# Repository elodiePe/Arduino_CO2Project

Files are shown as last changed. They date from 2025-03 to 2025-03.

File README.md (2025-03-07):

# GameAir

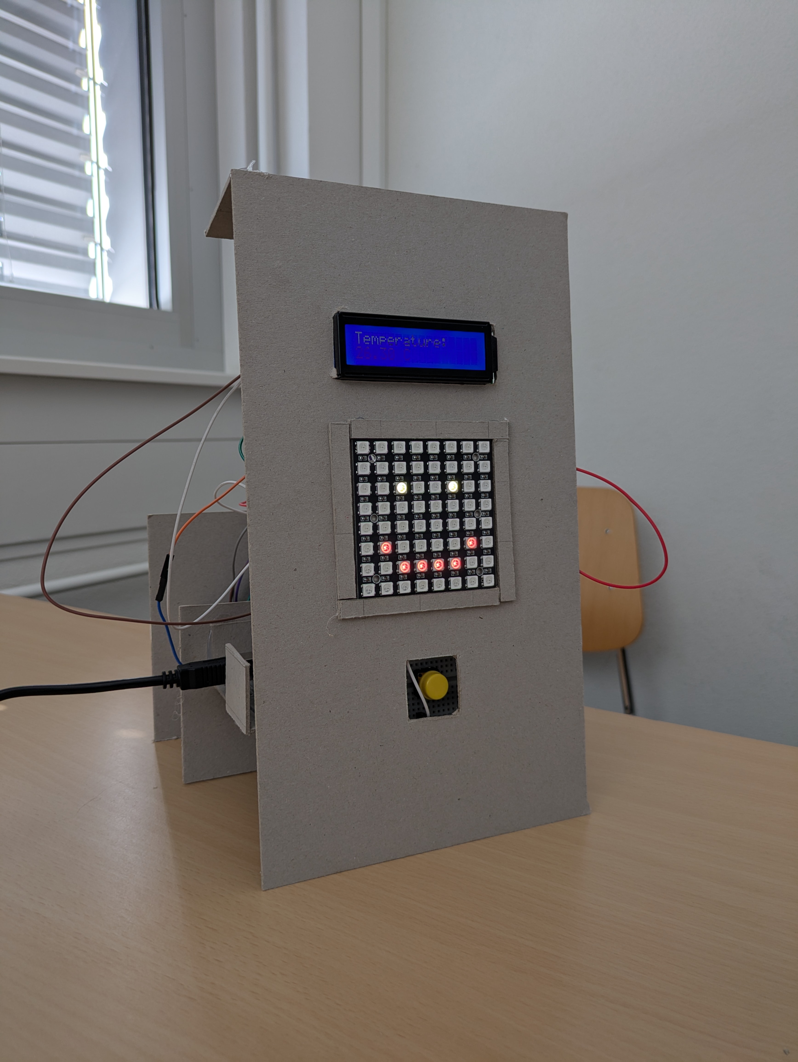
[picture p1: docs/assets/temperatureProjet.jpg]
Description de l'image


Réalisé par `Elodie Perring`
Option Arduino 2025 – COMEM+

---

## Description

`GameAir est un projet Arduino qui a pour but de détecter la qualité de l'air. Ce projet utilise plusieurs composants : un détecteur de CO2, un détecteur de température/humidité, un détecteur de mouvement,une matrice de LED rgb, un écran LCD ainsi qu'un bouton.`

## Documentation

Retrouvez la documentation dans le dossier [docs](docs/).

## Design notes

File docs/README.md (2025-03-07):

# Documentation

## Recherche et conception

Dans les salles de classe, il fait souvent chaud et elles manquent d'aération, ce qui réduit la quantité d'oxygène disponible et impacte la concentration. C'est pour cette raison que j'ai saisi l'opportunité de créer un détecteur de qualité de l'air afin de remédier à ce problème.

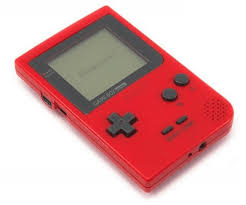
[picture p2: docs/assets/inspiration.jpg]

>Source : https://www.u-buy.ch/fr/product/47MMJS6W0-authentic-nintendo-gameboy-pocket-red-100-oem

Pour rendre le dispositif à la fois ludique et attrayant, je me suis inspirée du design des Game Boys et des anciennes consoles de jeux vidéo. Le projet, baptisé GameAir, propose plusieurs fonctionnalités afin d’offrir une expérience complète et utile :

- **Affichage de la température sur un écran LCD** : En fonction de la température (chaud, froid ou tempéré), un smiley correspondant apparaît sur la matrice de LED RGB.

- **Affichage du taux d'humidité** : plus le taux d'humidité est élevé, plus les LEDs s'allument sur la matrice pour une représentation visuelle immédiate.!
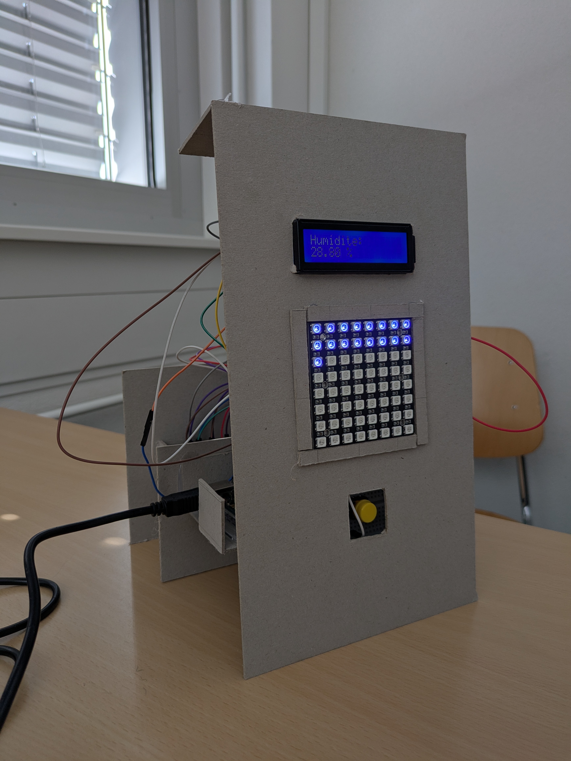
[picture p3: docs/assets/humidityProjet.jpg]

- **Affichage du niveau de CO2** : lorsque le taux de CO2 dépasse 1000 ppm (sur la photo et la video la limite est à 400), un symbole d'alerte apparaît sur la matrice de LED, et un buzzer retentit toutes les 3 minutes tant que la concentration reste trop élevée. [Voir la video](video_projet.mp4)
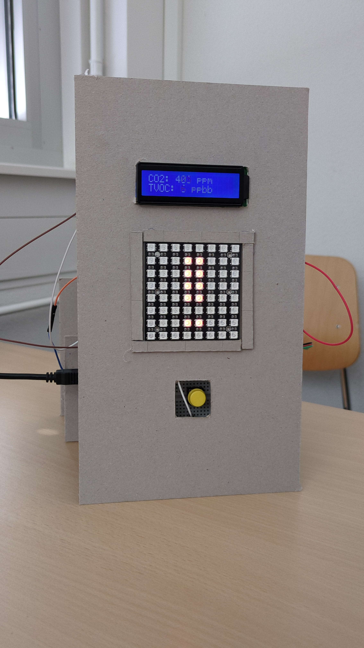
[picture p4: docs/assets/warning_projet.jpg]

- **Détecteur de mouvement intégré** : si aucune présence n'est détectée, les écrans restent éteints. En revanche, dès qu'une personne est présente, les écrans s'allument automatiquement.

### Mes prototypes

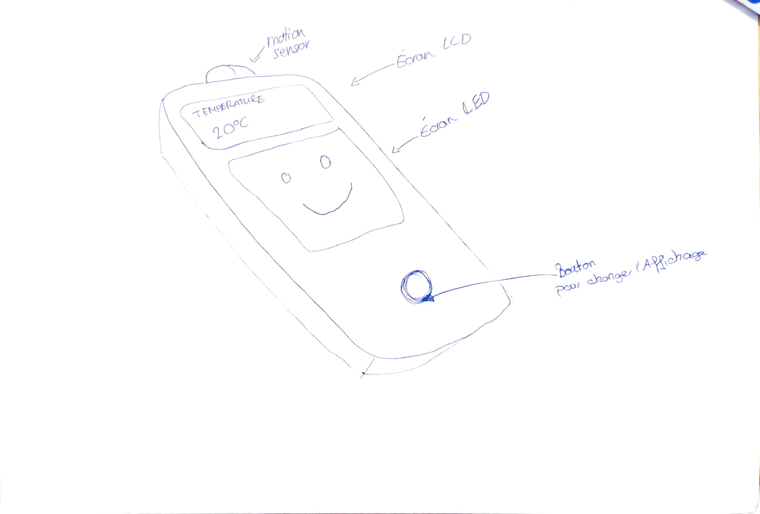
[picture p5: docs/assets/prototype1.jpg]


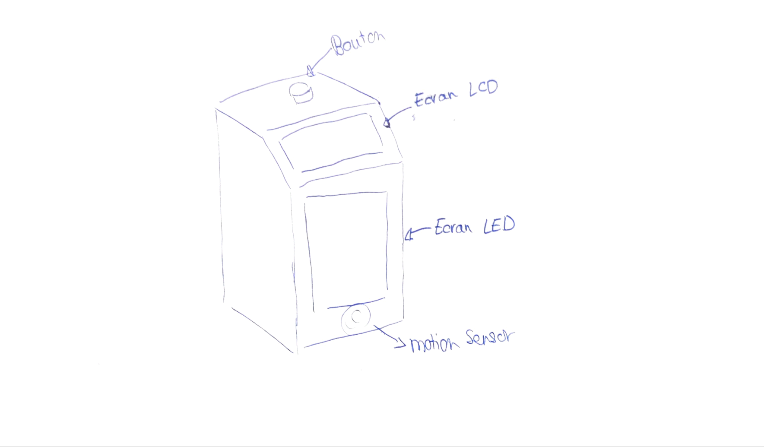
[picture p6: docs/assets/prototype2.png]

<br>

## Circuit électronique

Lors de ce projet, j'ai utilisé plusieurs composants et principalement des capteurs : 
- **Matrice de LED** : J'ai commencé par utiliser [une matrice LED rouge 16x16](matriceLed.md), mais comme le rendu n'étais pas convainquant, j'ai décidé de changer de matrice et d'utiliser la [8X8 matrice RGB de Purecrea](https://download.bastelgarage.ch/Datasheet/WS2812_Datasheet.pdf). Cette matrice est beaucoup plus simple à utiliser notamement grâce aux librairies déjà existantes.
- **Ecran LCD** : Grâce à la librairie déjà existante, cet écran est simple à utiliser. [Lien vers la datasheet](https://cdn-shop.adafruit.com/datasheets/TC1602A-01T.pdf)
- **Buzzer Piezo**
- **Capteur de mouvement** : J'ai utilisé le [PIR HC-SR501](motion.md)
- **Capteur de C02** : J'ai utiliser le [SGP30](co2.md)
- **Capteur de température & de l'humidité** : J'ai utilisé le [DHT11 temperature and humidity sensor](temp.md)

### Schéma

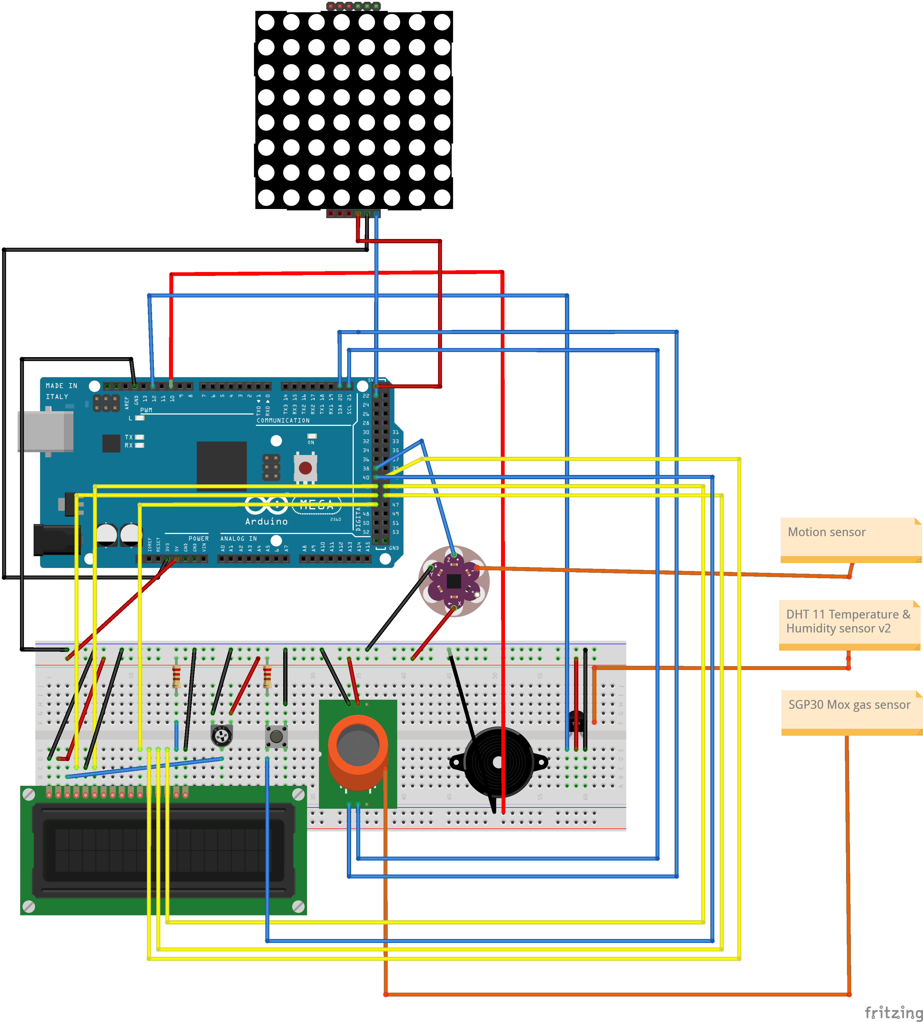
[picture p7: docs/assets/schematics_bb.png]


### BOM

|  | Composant | Quantité | Description | Fournisseur / Lien |
| --- | --- | --- | --- | --- |
| 1 | arduino mega 2560 | 1 | microcontroller  ATmega2560 | [Arduino](https://store.arduino.cc/products/arduino-mega-2560-rev3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) |
| 2 | Breadboard | 2 | Plaque de prototypage | [Digitec](https://www.digitec.ch/en/s1/product/velleman-high-quality-plug-in-board-electronics-supplies-casing-6337139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) |
| 3 | LCD screen  | 1 | 16x2 (6,6cm) | [Conrad](https://www.conrad.ch/de/p/joy-it-com-lcd-16x2-display-modul-6-6-cm-2-6-zoll-16-x-4-pixel-passend-fuer-entwicklungskits-arduino-mit-hintergrund-1656369.html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) |
| 4  | Buzzer Piezo  | 1 | 1,5V | [Digikey](https://www.digikey.ch/de/products/detail/murata-electronics/PKM22EPPH2001-B0/1219322?productid=1219322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)
| 5 | 8x8 LED matrix  | 1 | Purecrea NeoPixel NeoMatrix 8x8 - 64 WS2812 RGB LED | [Digitec](https://www.digitec.ch/de/s1/product/purecrea-neopixel-neomatrix-8x8-64-ws2812-rgb-led-aktive-bauelemente-36133371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) 
| 6 | Détecteur de mouvements  | 1 | Module détecteur de mouvement PIR Purecrea HC-SR501 | [Digitec](https://www.digitec.ch/de/s1/product/purecrea-hc-sr501-pir-bewegungsmelder-modul-entwicklungsboard-kit-39552366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) 
| 7 | Gas Sensor SGP30  | 1 | Gaz, humidité, qualité de l'air intérieur (QAI) | [DigiKey](https://www.digikey.ch/de/products/detail/adafruit-industries-llc/3709/8258468?productid=8258468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)  
| 8 | Temperature and humidity sensor  | 1 | DHT11 Temperature and Humidity Sensor  | [DFrobot](https://wiki.dfrobot.com/DHT11_Temperature_and_Humidity_Sensor__SKU__DFR0067_) 
| 9 | Bouton  | 1 | Bouton  | [Digitec](https://www.digitec.ch/de/s1/product/purecrea-taster-button-set-25-stueck-diverse-farben-taster-schalter-39044933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) 
| 10 | Resitance  | 2 | Résitances  | [DFrobot](https://www.digitec.ch/de/s1/product/kemo-widerstands-set-widerstand-21606532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) 
| 11 | Potentiomètre  | 1 | Potentiomètre  | [Digitec](https://www.digitec.ch/de/s1/product/purecrea-10k-ohm-linear-drehpotentiometer-3386p-1-103-potentiometer-passive-bauelemente-36225564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) 

## Programme
Dans ce projet, j'ai utilisé plusieurs librairies pour optimiser les fonctionnalités. La librairie LiquidCrystal me permet de gérer l'affichage sur un écran LCD, essentiel pour afficher des informations comme la température, l'humidité ou encore le niveau de CO2. J'ai également utilisé la librairie DHT pour le capteur d'humidité et de température, et Adafruit_SGP30 pour le capteur de qualité de l'air, mesurant le CO2 et les TVOC. Pour rendre l'interface plus visuelle et ludique, j'ai intégré la librairie FastLED afin de contrôler une matrice LED RGB 8x8, qui affiche des smileys et des indicateurs en fonction des données mesurées.
Pour éviter les rebonds du bouton et permettre au code de gérer plusieurs tâches en parallèle, j'ai utilisé la fonction millis(), ce qui permet de ne pas interrompre le fonctionnement du programme.

## Roadmap
Il y a encore plusieurs points à améliorer dans le projet. Par exemple, le buzzer ne peut pas être arrêté une fois activé, ce qui pourrait rapidement devenir agaçant. De plus, les visuels affichés sur la matrice de LED sont pour l'instant très statiques. Pour rendre l'appareil plus interactif et attractif, il serait intéressant de rendre ces visuels animés ou de les rendre plus dynamiques et détaillés, en intégrant par exemple des transitions ou des animations plus sophistiquées.

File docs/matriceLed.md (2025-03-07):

# Matrice LED 16x16
[Cette matrice](https://www.wiltronics.com.au/product/19744/dot-matrix-16x16-red-led-display-module-arduino-compatible/) de 16x16 (leds rouges) a très peu de documentation en ligne.
## Exemple de code pour afficher des smileys
```C++
// Définition des broches pour le contrôle des LED
const int LEDARRAY_D = 2;
const int LEDARRAY_C = 3;
const int LEDARRAY_B = 4;
const int LEDARRAY_A = 5;
const int LEDARRAY_G = 6;
const int LEDARRAY_DI = 7;
const int LEDARRAY_CLK = 8;
const int LEDARRAY_LAT = 9;

// Le nombre de mots et de caractères à afficher
const int DISPLAY_NUM_WORD = 2;
const int NUM_OF_WORD = 2; // 5 lettres pour "pluie"

unsigned char displayBuffer[8];
unsigned char displaySwapBuffer[DISPLAY_NUM_WORD][32] = { 0 };
bool shiftBit = 0;
bool flagShift = 0;
unsigned char timerCount = 0;
unsigned char temp = 0x80;
unsigned char shiftCount = 0;
unsigned char displayWordCount = 0;
const char happySmiley[2][32] = {
//hAPPY sMILEY
0xF8, 0xE0, 0xC0, 0x86, 0x86,0x06,0x00, 0x20, 
0x30, 0x18, 0x8C, 0x87,0xC0, 0xE0, 0xF8, 0xFF, 
0x3F, 0x0F, 0x07, 0xC3, 0xC3, 0xC1, 0x01, 0x09, 
0x19, 0x31, 0x63, 0xC3, 0x07, 0x0F, 0x3F, 0xFF,
};

const char coldSmiley[2][32] = {
// COLD SMILEY 
0xFF, 0xFF, 0xE7, 0xDB, 0xFF, 0xE7, 0xE7, 0xFF,
0xFF, 0xC0, 0xD6, 0xDA, 0xC0, 0xFF, 0xFF, 0xFF,
0xFF, 0xFF, 0xCF, 0xB7, 0xFF, 0xCF, 0xCF, 0xFF,
0xFF, 0x07, 0xD7, 0xB7, 0x07, 0xFF, 0xFF, 0xFF,
};

const char sunSmiley[2][32] = {
// SMILEY SUN
0xFF, 0xFF, 0x02, 0x80, 0x82, 0x87, 0xFF, 0xFF,
0x3F, 0xDF, 0xCF, 0xEF, 0xF0, 0xFF, 0xFF, 0xFF,
0xFF, 0xFF, 0x07, 0x0F, 0x0F, 0x0F, 0xFF, 0xFF,
0xE7, 0xCF, 0x9F, 0xBF, 0x7F, 0xFF, 0xFF, 0xFF,
};
const char warning[2][32] = {
// WARNING SIGN
0xFF, 0xFE, 0xFD, 0xFB, 0xFA, 0xF6, 0xF6, 0xE6,
0xEE, 0xEF, 0xCE, 0xDE, 0x9F, 0xBF, 0x80, 0xFF,
0x7F, 0x3F, 0xDF, 0xEF, 0x2F, 0x37, 0x37, 0x33, 
0x3B, 0xFB, 0x39, 0x3D, 0x03, 0x01, 0x00, 0xFF,
};

const char (*MESSAGE)[32];

void setup() {
  pinMode(LEDARRAY_D, OUTPUT);
  pinMode(LEDARRAY_C, OUTPUT);
  pinMode(LEDARRAY_B, OUTPUT);
  pinMode(LEDARRAY_A, OUTPUT);
  pinMode(LEDARRAY_G, OUTPUT);
  pinMode(LEDARRAY_DI, OUTPUT);
  pinMode(LEDARRAY_CLK, OUTPUT);
  pinMode(LEDARRAY_LAT, OUTPUT);
  changeDisplay(happySmiley);
  cleardisplay();
}

void loop() {
  for (int i = 0; i < 30; i++) {
    display(displaySwapBuffer);
  }
  displayWordCount = shiftCount / 16;
  calcShift();
  shiftCount++;
  if (shiftCount == (NUM_OF_WORD + DISPLAY_NUM_WORD) * 16) {
    shiftCount = 0;
  }
}
void changeDisplay(const char (*newMessage)[32]) {
  // Met à jour le message que le tableau "MESSAGE" va contenir
  MESSAGE = newMessage; 
  cleardisplay();  // Efface l'écran avant d'afficher un nouveau message
}

void cleardisplay() {
  for (int j = 0; j < DISPLAY_NUM_WORD; j++) {
    for (int i = 0; i < 32; i++) {
      displaySwapBuffer[j][i] = 0xFF;
    }
  }
}

void calcShift() {
  unsigned char i;

  for (i = 0; i < 16; i++) {
    if ((displaySwapBuffer[0][16 + i] & 0x80) == 0) {
      displaySwapBuffer[0][i] = (displaySwapBuffer[0][i] << 1) & 0xfe;
    } else {
      displaySwapBuffer[0][i] = (displaySwapBuffer[0][i] << 1) | 0x01;
    }

    if ((displaySwapBuffer[1][i] & 0x80) == 0) {
      displaySwapBuffer[0][16 + i] = (displaySwapBuffer[0][16 + i] << 1) & 0xfe;
    } else {
      displaySwapBuffer[0][16 + i] = (displaySwapBuffer[0][16 + i] << 1) | 0x01;
    }

    if ((displaySwapBuffer[1][16 + i] & 0x80) == 0) {
      displaySwapBuffer[1][i] = (displaySwapBuffer[1][i] << 1) & 0xfe;
    } else {
      displaySwapBuffer[1][i] = (displaySwapBuffer[1][i] << 1) | 0x01;
    }

    if (shiftCount % 16 < 8 && displayWordCount < NUM_OF_WORD) {
      shiftBit = MESSAGE[displayWordCount][i] & temp;
    } else if (shiftCount % 16 < 16 && displayWordCount < NUM_OF_WORD) {
      shiftBit = MESSAGE[displayWordCount][16 + i] & temp;
    } else {
      shiftBit = 1;
    }

    if (shiftBit == 0) {
      displaySwapBuffer[1][16 + i] = (displaySwapBuffer[1][16 + i] << 1) & 0xfe;
    } else {
      shiftBit = 1;
      displaySwapBuffer[1][16 + i] = (displaySwapBuffer[1][16 + i] << 1) | 0x01;
    }
  }
  temp = (temp >> 1) & 0x7f;
  if (temp == 0x00) {
    temp = 0x80;
  }
}

void scanLine(unsigned char m) {
  switch (m) {
    case 0:
      digitalWrite(LEDARRAY_D, LOW);
      digitalWrite(LEDARRAY_C, LOW);
      digitalWrite(LEDARRAY_B, LOW);
      digitalWrite(LEDARRAY_A, LOW);
      break;
    case 1:
      digitalWrite(LEDARRAY_D, LOW);
      digitalWrite(LEDARRAY_C, LOW);
      digitalWrite(LEDARRAY_B, LOW);
      digitalWrite(LEDARRAY_A, HIGH);
      break;
    case 2:
      digitalWrite(LEDARRAY_D, LOW);
      digitalWrite(LEDARRAY_C, LOW);
      digitalWrite(LEDARRAY_B, HIGH);
      digitalWrite(LEDARRAY_A, LOW);
      break;
    case 3:
      digitalWrite(LEDARRAY_D, LOW);
      digitalWrite(LEDARRAY_C, LOW);
      digitalWrite(LEDARRAY_B, HIGH);
      digitalWrite(LEDARRAY_A, HIGH);
      break;
    case 4:
      digitalWrite(LEDARRAY_D, LOW);
      digitalWrite(LEDARRAY_C, HIGH);
      digitalWrite(LEDARRAY_B, LOW);
      digitalWrite(LEDARRAY_A, LOW);
      break;
    case 5:
      digitalWrite(LEDARRAY_D, LOW);
      digitalWrite(LEDARRAY_C, HIGH);
      digitalWrite(LEDARRAY_B, LOW);
      digitalWrite(LEDARRAY_A, HIGH);
      break;
    case 6:
      digitalWrite(LEDARRAY_D, LOW);
      digitalWrite(LEDARRAY_C, HIGH);
      digitalWrite(LEDARRAY_B, HIGH);
      digitalWrite(LEDARRAY_A, LOW);
      break;
    case 7:
      digitalWrite(LEDARRAY_D, LOW);
      digitalWrite(LEDARRAY_C, HIGH);
      digitalWrite(LEDARRAY_B, HIGH);
      digitalWrite(LEDARRAY_A, HIGH);
      break;
    case 8:
      digitalWrite(LEDARRAY_D, HIGH);
      digitalWrite(LEDARRAY_C, LOW);
      digitalWrite(LEDARRAY_B, LOW);
      digitalWrite(LEDARRAY_A, LOW);
      break;
    case 9:
      digitalWrite(LEDARRAY_D, HIGH);
      digitalWrite(LEDARRAY_C, LOW);
      digitalWrite(LEDARRAY_B, LOW);
      digitalWrite(LEDARRAY_A, HIGH);
      break;
    case 10:
      digitalWrite(LEDARRAY_D, HIGH);
      digitalWrite(LEDARRAY_C, LOW);
      digitalWrite(LEDARRAY_B, HIGH);
      digitalWrite(LEDARRAY_A, LOW);
      break;
    case 11:
      digitalWrite(LEDARRAY_D, HIGH);
      digitalWrite(LEDARRAY_C, LOW);
      digitalWrite(LEDARRAY_B, HIGH);
      digitalWrite(LEDARRAY_A, HIGH);
      break;
    case 12:
      digitalWrite(LEDARRAY_D, HIGH);
      digitalWrite(LEDARRAY_C, HIGH);
      digitalWrite(LEDARRAY_B, LOW);
      digitalWrite(LEDARRAY_A, LOW);
      break;
    case 13:
      digitalWrite(LEDARRAY_D, HIGH);
      digitalWrite(LEDARRAY_C, HIGH);
      digitalWrite(LEDARRAY_B, LOW);
      digitalWrite(LEDARRAY_A, HIGH);
      break;
    case 14:
      digitalWrite(LEDARRAY_D, HIGH);
      digitalWrite(LEDARRAY_C, HIGH);
      digitalWrite(LEDARRAY_B, HIGH);
      digitalWrite(LEDARRAY_A, LOW);
      break;
    case 15:
      digitalWrite(LEDARRAY_D, HIGH);
      digitalWrite(LEDARRAY_C, HIGH);
      digitalWrite(LEDARRAY_B, HIGH);
      digitalWrite(LEDARRAY_A, HIGH);
      break;
    default:
      break;
  }
}

void send(unsigned char dat) {
  unsigned char i;
  digitalWrite(LEDARRAY_CLK, LOW);
  delayMicroseconds(1);
  digitalWrite(LEDARRAY_LAT, LOW);
  delayMicroseconds(1);

  for (i = 0; i < 8; i++) {
    if (dat & 0x01) {
      digitalWrite(LEDARRAY_DI, HIGH);
    } else {
      digitalWrite(LEDARRAY_DI, LOW);
    }
    digitalWrite(LEDARRAY_CLK, HIGH);
    delayMicroseconds(1);
    digitalWrite(LEDARRAY_CLK, LOW);
    delayMicroseconds(1);
    dat >>= 1;
  }
}

void display(const unsigned char dat[][32]) {
  unsigned char i;

  for (i = 0; i < 16; i++) {
    digitalWrite(LEDARRAY_G, HIGH);

    displayBuffer[0] = dat[0][i];
    displayBuffer[1] = dat[0][i + 16];
    displayBuffer[2] = dat[1][i];
    displayBuffer[3] = dat[1][i + 16];

    displayBuffer[4] = dat[2][i];
    displayBuffer[5] = dat[2][i + 16];
    displayBuffer[6] = dat[3][i];
    displayBuffer[7] = dat[3][i + 16];

    send(displayBuffer[7]);
    send(displayBuffer[6]);
    send(displayBuffer[5]);
    send(displayBuffer[4]);

    send(displayBuffer[3]);
    send(displayBuffer[2]);
    send(displayBuffer[1]);
    send(displayBuffer[0]);

    digitalWrite(LEDARRAY_LAT, HIGH);
    delayMicroseconds(1);

    digitalWrite(LEDARRAY_LAT, LOW);
    delayMicroseconds(1);

    scanLine(i);

    digitalWrite(LEDARRAY_G, LOW);

    delayMicroseconds(300);
  }
}
```

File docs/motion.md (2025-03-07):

# Capteur de présence
https://www.moussasoft.com/capteur-de-mouvement-pir-hc-sr501/
## Exemple de code
```c++
// Define the pins

const int ledPin = 4;
const int motionSensor = 2;

void setup() {
  Serial.begin(9600);
pinMode(motionSensor, INPUT);
  pinMode(ledPin, OUTPUT);
}

void loop() {
int sensorValue = digitalRead(motionSensor);
if (sensorValue == HIGH){
  Serial.println("allumé");
  digitalWrite(ledPin, HIGH);
  delay(1000);
} else {
    Serial.println("Eteint");
  digitalWrite(ledPin, LOW);
}
}
```
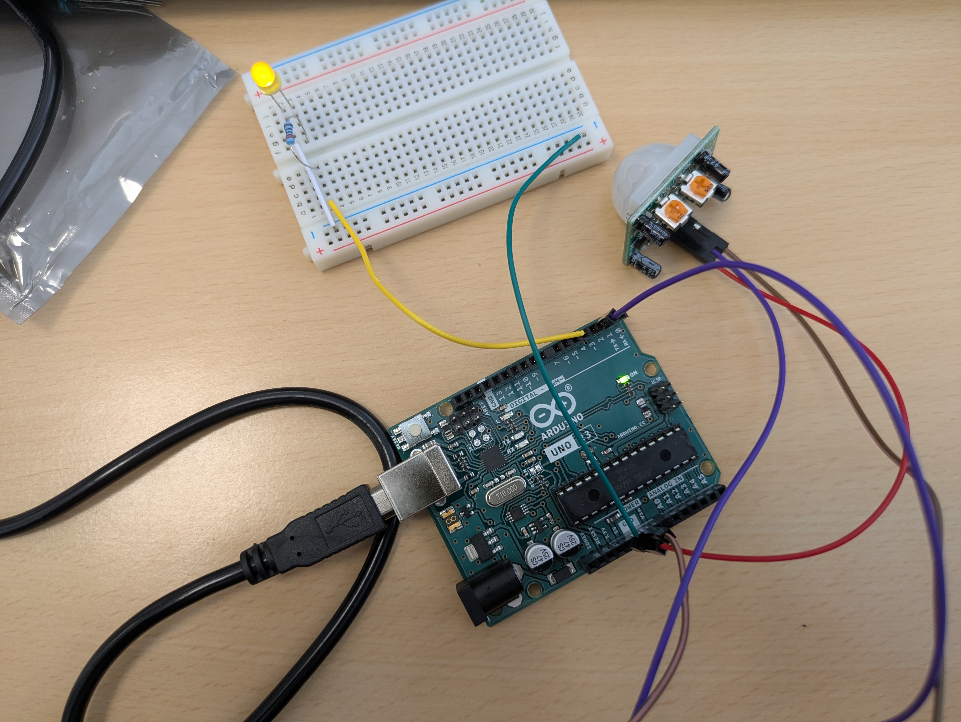
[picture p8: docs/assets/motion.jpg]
Description de l'image


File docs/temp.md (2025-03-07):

# Temperature et humidité
- [Lien vers la documentation](https://projecthub.arduino.cc/rudraksh2008/temperature-and-humidity-sensor-with-arduino-1d52a6)
## Exemple de code
```c++
// Inclure les bibliothèques DHT et Adafruit Unified Sensor

#include <DHT.h>
#include <Adafruit_Sensor.h>

// Définir le type de capteur DHT et la broche de données

#define DHTPIN 3    
// Pin à laquelle le DHT est connecté

#define DHTTYPE DHT11   // DHT 11 (ou utilisez DHT22 pour le capteur DHT22)

// Initialisation du capteur DHT
DHT dht(DHTPIN, DHTTYPE);

void setup() {
  // Démarrer la communication série
  Serial.begin(9600);
  Serial.println("DHT11 Sensor - Temperature and Humidity");
  
  // Démarrer le capteur DHT
dht.begin();
}
void loop() {

  // Attendre 2 secondes entre les mesures
  delay(2000);
  
  // Lire l'humidité
  float humidity = dht.readHumidity();

  // Lire la température en Celsius
  float temperature = dht.readTemperature();
  
  // Vérifier si les lectures ont échoué et sortir si c'est le cas
  if (isnan(humidity) || isnan(temperature)) {
    Serial.println("Erreur de lecture du capteur DHT!");
    return;
  }
  
  // Afficher les résultats sur le moniteur série
  Serial.print("Humidité: ");
  Serial.print(humidity);
  Serial.println(" %");

  Serial.print("Température: ");
  Serial.print(temperature);
  Serial.println(" °C");
}
```

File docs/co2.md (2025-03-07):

# Détecteur de CO2
- [Lien vers la documentation du SGP30](https://cdn-learn.adafruit.com/downloads/pdf/adafruit-sgp30-gas-tvoc-eco2-mox-sensor.pdf)

## Exemple de code
```c++
#include <Wire.h>
#include "Adafruit_SGP30.h"

// Initialisation du capteur SGP30
Adafruit_SGP30 sgp;

void setup() {
  Serial.begin(9600);
  Serial.println("Initialisation du capteur SGP30...");

  if (!sgp.begin()) {
    Serial.println("Erreur : Le capteur SGP30 n'a pas pu être trouvé.");
    while (1);
  }
  Serial.println("Capteur SGP30 initialisé avec succès.");

  // Démarrer la mesure d'air TVOC et eCO2
  if (!sgp.IAQinit()) {
    Serial.println("Erreur lors de l'initialisation IAQ.");
  }
}

void loop() {
  if (!sgp.IAQmeasure()) {
    Serial.println("Erreur lors de la mesure de la qualité de l'air.");
    return;
  }

  // Affichage de la concentration de CO2 équivalent (eCO2) en ppm
  Serial.print("CO2 équivalent (eCO2) : ");
  Serial.print(sgp.eCO2);
  Serial.println(" ppm");

  // Affichage de la concentration de COV totaux (TVOC) en ppb
  Serial.print("COV totaux (TVOC) : ");
  Serial.print(sgp.TVOC);
  Serial.println(" ppb");

  delay(1000); // Attendre 1 seconde avant la prochaine lecture
}

```

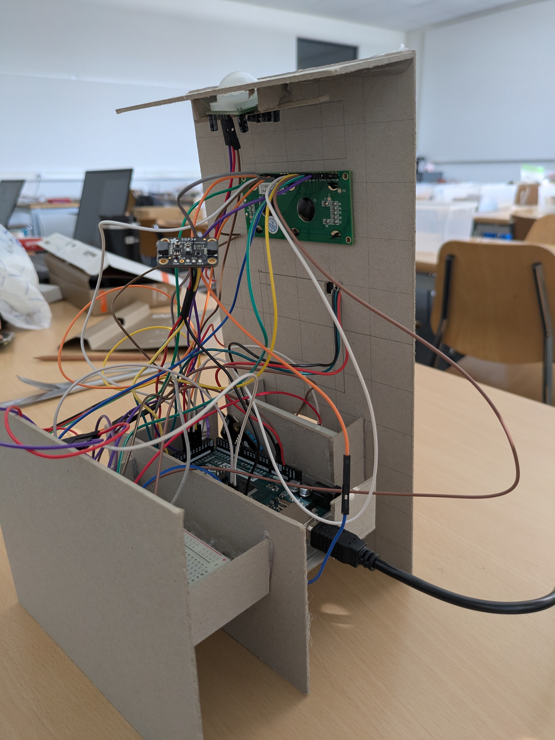
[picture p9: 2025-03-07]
docs/assets/arriere_projet.jpg

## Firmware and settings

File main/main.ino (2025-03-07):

#include <LiquidCrystal.h>
#include <DHT.h>
#include <Adafruit_Sensor.h>
#include <Wire.h>
#include <Adafruit_SGP30.h>
#include <FastLED.h>


#define DHTPIN 12
#define DHTTYPE DHT11

// initialisation des capteurs DHT et SGP30
DHT dht(DHTPIN, DHTTYPE);
Adafruit_SGP30 sgp;

//matrice led
#define NUM_LEDS 64
#define DATA_PIN 22
#define BRIGHTNESS 10
#define MATRIX_WIDTH 8
#define MATRIX_HEIGHT 8

CRGB leds[NUM_LEDS];


// buzzer
int buzzerPin = 10;

int melody[] = {
  262, 294, 330, 349, 392, 440, 494, 523  // Do, Ré, Mi, Fa, Sol, La, Si, Do
};
int noteDuration = 500;
unsigned long previousMillis = 0;
unsigned long previousMelodyMillis = 0;
const unsigned long interval = 18000;
int noteIndex = 0;
bool isPlaying = false;

//LCD
const int rs = 44, en = 42, d4 = 46, d5 = 41, d6 = 45, d7 = 43;
LiquidCrystal lcd(rs, en, d4, d5, d6, d7);

// pin for presence detector (PIR sensor)
const int PIR_PIN = 38;
int pirState = LOW;

// button
const int BUTTON_PIN = 40;
int buttonState = HIGH;
int lastButtonState = HIGH;
int pressed = 0;
const unsigned long DEBOUNCE_DELAY = 50;
unsigned long lastDebounceTime = 0;

void setup() {

  dht.begin();

  lcd.begin(16, 2);
  pinMode(BUTTON_PIN, INPUT_PULLUP);


  pinMode(PIR_PIN, INPUT);

  if (!sgp.begin()) {
    Serial.println("Erreur : Le capteur SGP30 n'a pas pu être trouvé.");
    while (1)
      ;
  }
  Serial.println("Capteur SGP30 initialisé avec succès.");



  if (!sgp.IAQinit()) {
    Serial.println("Erreur lors de l'initialisation IAQ.");
  }

  pinMode(buzzerPin, OUTPUT);
  tone(buzzerPin, melody[0], noteDuration);
  FastLED.addLeds<WS2812, DATA_PIN, GRB>(leds, NUM_LEDS);
  FastLED.setBrightness(BRIGHTNESS);
  turnOffLeds();
  Serial.begin(9600);
}

void loop() {
  unsigned long currentMillis = millis();


  int pirVal = digitalRead(PIR_PIN);
  if (pirVal == HIGH && pirState == LOW) {

    pirState = HIGH;
    lcd.display();
    Serial.println("Présence détectée, écran allumé.");
  } else if (pirVal == LOW && pirState == HIGH) {
    pirState = LOW;
    lcd.noDisplay();
    turnOffLeds();
    Serial.println("Pas de présence, écran éteint.");
  }

  if (!sgp.IAQmeasure()) {
    Serial.println("Erreur lors de la mesure de la qualité de l'air.");
    return;
  };

  // Gestion du bouton
  int currentButtonState = digitalRead(BUTTON_PIN);

  if (currentButtonState != lastButtonState) {
    lastDebounceTime = millis();
  }
  if ((millis() - lastDebounceTime) > DEBOUNCE_DELAY) {
    if (currentButtonState != buttonState) {
      buttonState = currentButtonState;

      if (buttonState == LOW) {
        pressed++;
        lcd.clear();
        if (pressed > 2) {
          pressed = 0;
        }
        Serial.println("🔘 Appuyé !");
      }
    }
  }

  float humidity = dht.readHumidity();
  float temperature = dht.readTemperature();

  if (pressed == 0 && pirVal == HIGH) {
    lcd.clear();
    lcd.setCursor(0, 0);
    lcd.print("Temperature: ");
    lcd.setCursor(0, 1);
    lcd.print(temperature);
    lcd.print(" C");
    if (temperature < 10 && sgp.eCO2 < 1000) {
      drawSadSmiley();
    };
    if (temperature < 20 && temperature > 10 && sgp.eCO2 < 1000) {
      drawNeutralSmiley();
    }
    if (temperature > 20 && sgp.eCO2 < 1000) {
      drawHappySmiley();
    }
    if (temperature == 20) {
      drawHappySmiley;
    }

  } else if (pressed == 1 && pirVal == HIGH) {
    lcd.setCursor(0, 0);
    lcd.print("Humidite: ");
    lcd.setCursor(0, 1);
    lcd.print(humidity);
    lcd.print(" %");
    if (sgp.eCO2 < 1000) {
      drawHumidityDisplay(humidity);
    }
  } else if (pressed == 2 && pirVal == HIGH) {
    lcd.setCursor(0, 0);
    lcd.print("CO2: ");
    lcd.print(sgp.eCO2);
    lcd.print(" ppm");
    lcd.setCursor(0, 1);
    lcd.print("TVOC: ");
    lcd.print(sgp.TVOC);
    lcd.print(" ppb");
    if (sgp.eCO2 > 1000) {
      drawWarningSign();
    } else {
      drawHappySmiley();
    }
  }
  if (sgp.eCO2 > 1000) {
    drawWarningSign();
    if (currentMillis - previousMelodyMillis >= interval && !isPlaying) {
      previousMelodyMillis = currentMillis;
      isPlaying = true;
      noteIndex = 0;
    }

    if (isPlaying) {
      if (currentMillis - previousMillis >= noteDuration) {
        previousMillis = currentMillis;

        noTone(buzzerPin);

        if (noteIndex < 8) {
          tone(buzzerPin, melody[noteIndex], noteDuration);
          noteIndex++;
        } else {
          isPlaying = false;
        }
      }
    }
  }
  if (pirVal == LOW && sgp.eCO2 < 1000) {
    turnOffLeds();
  }
  lastButtonState = currentButtonState;
}

int XY(int x, int y) {
  if (y % 2 == 0) {
    return (y * MATRIX_WIDTH) + x;
  } else {
    return (y * MATRIX_WIDTH) + (MATRIX_WIDTH - 1 - x);
  }
}

void drawHappySmiley() {
  fill_solid(leds, NUM_LEDS, CRGB::Black);
  leds[XY(2, 2)] = CRGB::Yellow;
  leds[XY(5, 2)] = CRGB::Yellow;
  leds[XY(1, 5)] = CRGB::Red;
  leds[XY(2, 6)] = CRGB::Red;
  leds[XY(3, 6)] = CRGB::Red;
  leds[XY(4, 6)] = CRGB::Red;
  leds[XY(5, 6)] = CRGB::Red;
  leds[XY(6, 5)] = CRGB::Red;
  FastLED.show();
}

void drawNeutralSmiley() {
  fill_solid(leds, NUM_LEDS, CRGB::Black);
  leds[XY(2, 2)] = CRGB::Yellow;
  leds[XY(5, 2)] = CRGB::Yellow;
  leds[XY(2, 6)] = CRGB::Red;
  leds[XY(3, 6)] = CRGB::Red;
  leds[XY(4, 6)] = CRGB::Red;
  leds[XY(5, 6)] = CRGB::Red;

  FastLED.show();
}


void drawSadSmiley() {
  fill_solid(leds, NUM_LEDS, CRGB::Black);
  leds[XY(2, 2)] = CRGB::Yellow;
  leds[XY(5, 2)] = CRGB::Yellow;
  leds[XY(1, 6)] = CRGB::Red;
  leds[XY(2, 5)] = CRGB::Red;
  leds[XY(3, 5)] = CRGB::Red;
  leds[XY(4, 5)] = CRGB::Red;
  leds[XY(5, 5)] = CRGB::Red;
  leds[XY(6, 6)] = CRGB::Red;

  FastLED.show();
}
void drawWarningSign() {

  fill_solid(leds, NUM_LEDS, CRGB::Black);

  leds[XY(3, 1)] = CRGB::Red;
  leds[XY(3, 2)] = CRGB::Red;
  leds[XY(3, 3)] = CRGB::Red;
  leds[XY(3, 4)] = CRGB::Red;
  leds[XY(4, 1)] = CRGB::Red;
  leds[XY(4, 2)] = CRGB::Red;
  leds[XY(4, 3)] = CRGB::Red;
  leds[XY(4, 4)] = CRGB::Red;

  leds[XY(3, 6)] = CRGB::Red;
  leds[XY(4, 6)] = CRGB::Red;

  FastLED.show();
}

void turnOffLeds() {
  fill_solid(leds, NUM_LEDS, CRGB::Black);
  FastLED.show();
}
void drawHumidityDisplay(float humidity) {

  if (humidity < 0) humidity = 0;
  if (humidity > 100) humidity = 100;

  int ledsToLightUp = map(humidity, 0, 100, 0, NUM_LEDS);

  fill_solid(leds, NUM_LEDS, CRGB::Black);

  for (int i = 0; i < ledsToLightUp; i++) {
    leds[i] = CRGB::Blue;
  }

  FastLED.show();
}

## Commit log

2025-03-03 Add initial project files, including .gitignore, README, documentation, and Arduino sketch
    [schematics.fzz]
2025-03-04 Add sensor integration and display functionality for temperature, humidity, and air quality
2025-03-06 Son, sensors, matrix fonctionnels
2025-03-06 Ajout de la nouvelle matrice
2025-03-06 Update thresholds for sensor readings and button state handling
2025-03-06 Add project assets and update documentation for GameAir
    [schematics.fzz]
2025-03-07 Ajout de la documentation
    [lcdDisplay.fzz]
2025-03-07 Update documentation and assets for GameAir project
    [lcdDisplay.fzz]
